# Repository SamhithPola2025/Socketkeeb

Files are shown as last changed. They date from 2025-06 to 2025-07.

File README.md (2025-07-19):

# Socketkeeb
Socketkeeb (keyboard) is a custom keyboard I designed in 4 days from PCB to CAD for HackClub's Highway program.
This keyboard was inspired by my need for a keyboard that had low profile switches because those are my favorite type of switches but I could not find a budget one anywhere, so I said why not just make it myself, because that's the solution to most things in life unless its rocket science.

# Challenges
- Designing a PCB compatible with both RP2040 and Kailh Choc switches  
- Sourcing components from multiple vendors while managing shipping costs  
- Ensuring 3D printed keycaps fit properly on low-profile switches  
- Aligning stabilizers and switches without a plate (plateless design quirks)  

# Why I made this
- I wanted a fully custom keyboard with low-profile Choc switches and RP2040 brain  
- I wanted to learn about PCB design, BOM creation, and firmware flashing  
- I like the idea of 3D printing keycaps for a unique personal touch  
- It’s a fun project to build something that’s truly mine from scratch  

# What went good
- Successfully generated a clean BOM and Markdown table for GitHub  
- Found all parts at reasonable prices from trusted vendors  
- 3D printed keycaps turned out better than expected using PLA  
- The design workflow in CAD + PCB tools was smoother than I thought

# BOM: (In BOM.csv too)
| Reference | Quantity | Value | Footprint | Manufacturer | Part Number | Description | Unit Price (USD) | Total Price (USD) | Source Link |
|---|---|---|---|---|---|---|---|---|---|
| STAB | 1 set | n/a | PCB Mount | Gateron | n/a | Gateron PCB-mounted stabilizer set (various sizes) | 8.00 | 8.00 | [Gateron](https://www.gateron.com/products/gateron-pcb-mounted-stabilizer?VariantsId=10208) |
| U1 | 1 | RP2040 | Pico W | Raspberry Pi | SC0918 | Raspberry Pi Pico W microcontroller | 7.65 | 7.65 | [DigiKey](https://www.digikey.com/en/products/detail/raspberry-pi/SC0918/16608263) |
| SW1-SW70 | 70 | Kailh Choc Violet | Kailh PG1350 | Kailh | PG1350 | Kailh low-profile Choc Violet switch (70 pcs) | 44.74 | 44.74 | [AliExpress](https://www.aliexpress.us/item/3256806826186563.html) |
| D1-D200 | 200 | 1N4148 | DO-35 | ON Semi | 1N4148 | 1N4148 100V 200mA diode (200 pcs) | 6.76 | 6.76 | [DigiKey](https://www.digikey.com/en/products/detail/onsemi/1N4148/458603) |
| KC1-KC70 | 70 | n/a | n/a | 3D printed | n/a | Custom 3D printed keycaps | 0.00 | 0.00 | n/a |
| **Subtotal** |  |  |  |  |  |  |  | **67.15** |  |
| **Estimated total (with shipping/tax rounded)** |  |  |  |  |  |  |  | **100.00** |  |

# Design Pictures:


Screenshot 2025-06-27 at 9 40 19 PM

# Build Pictures:
IMG_35EF4666-0DB9-4445-A45B-9BEA4F2A8813 2

## My printer broke down, not enough time for printing legion, have to go to Barcelona tommorow. Decided to 3D print what I could, and I got permission to submit demo form without keycaps. Hope that clears up a few things regarding the demo video!

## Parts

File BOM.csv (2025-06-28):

BOM
Reference | Quantity | Value | Footprint | Manufacturer | Part Number | Description | Unit Price (USD) | Total Price (USD) | Source Link
STAB | 1 set | N/a | PCB Mount | Gateron | N/a | Gateron PCB-mounted stabilizer set (various sizes) | 8.00 | 8.00 | https://www.gateron.com/products/gateron-pcb-mounted-stabilizer?VariantsId=10208
U1 | 1 | RP2040 | Pico W | Raspberry Pi | SC0918 | Raspberry Pi Pico W microcontroller | 7.65 | 7.65 | https://www.digikey.com/en/products/detail/raspberry-pi/SC0918/16608263
SW1-SW70 | 70 | Kailh Choc Violet | Kailh PG1350 | Kailh | PG1350 | Kailh low-profile Choc Violet switch (70 pcs) | 44.74 | 44.74 | https://www.aliexpress.us/item/3256806826186563.html
D1-D200 | 200 | 1N4148 | DO-35 | ON Semi | 1N4148 | 1N4148 100V 200mA diode (200 pcs) | 6.76 | 6.76 | https://www.digikey.com/en/products/detail/onsemi/1N4148/458603
KC1-KC70 | 70 | N/a | N/a | 3D printed | N/a | Custom 3D printed keycaps | 0.00 | 0.00 | N/a
PCB (full pcb) | 1 | PCB | N/a | JLCPCB | N/a | JLCPCB quote for the keyboard PCB | 20.00 | 20.00
Subtotal |  |  |  |  |  |  |  | 67.15
Estimated total (with shipping/tax rounded) |  |  |  |  |  |  |  | $100 (tax+shipping added and probably it all wont be used)

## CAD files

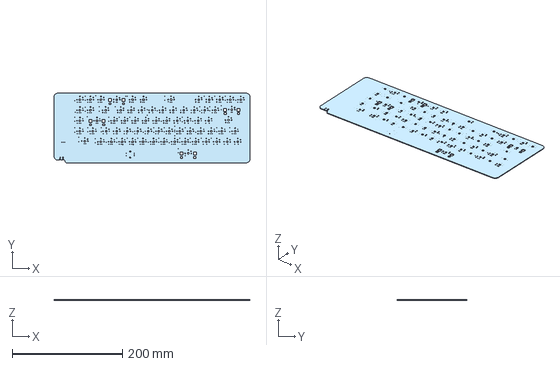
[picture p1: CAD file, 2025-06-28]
CAD/PLATESTEP.step
355.0 x 126.2 x 1.00 mm

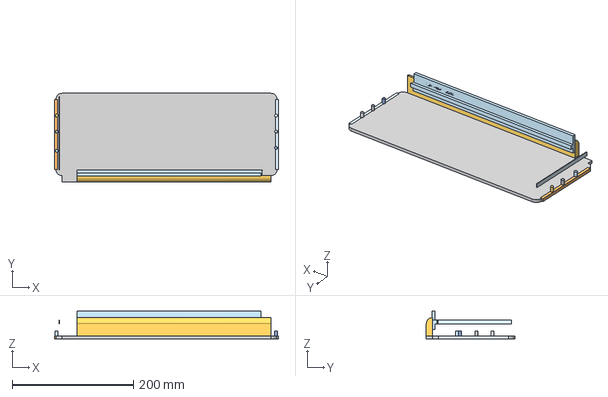
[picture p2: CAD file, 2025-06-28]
CAD/CASEBOTTOMBACKSIDESTEP.step
370.0 x 146.2 x 45.8 mm

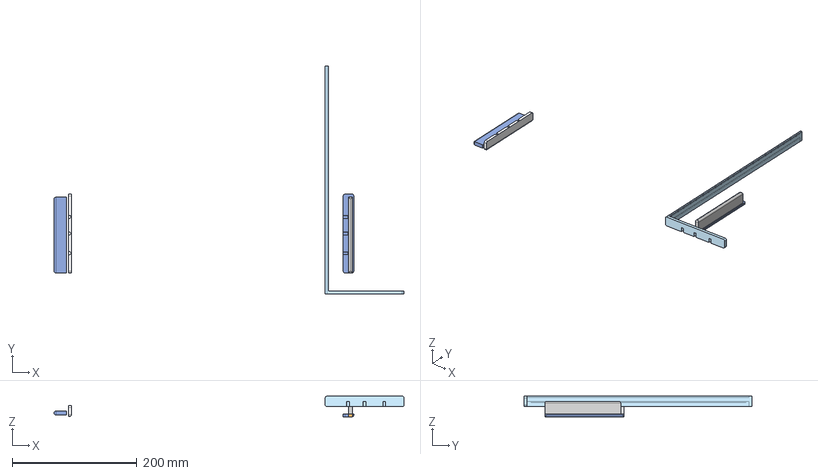
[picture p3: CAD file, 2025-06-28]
CAD/CASEWALLSSTEP.step
560.1 x 365.0 x 33.3 mm

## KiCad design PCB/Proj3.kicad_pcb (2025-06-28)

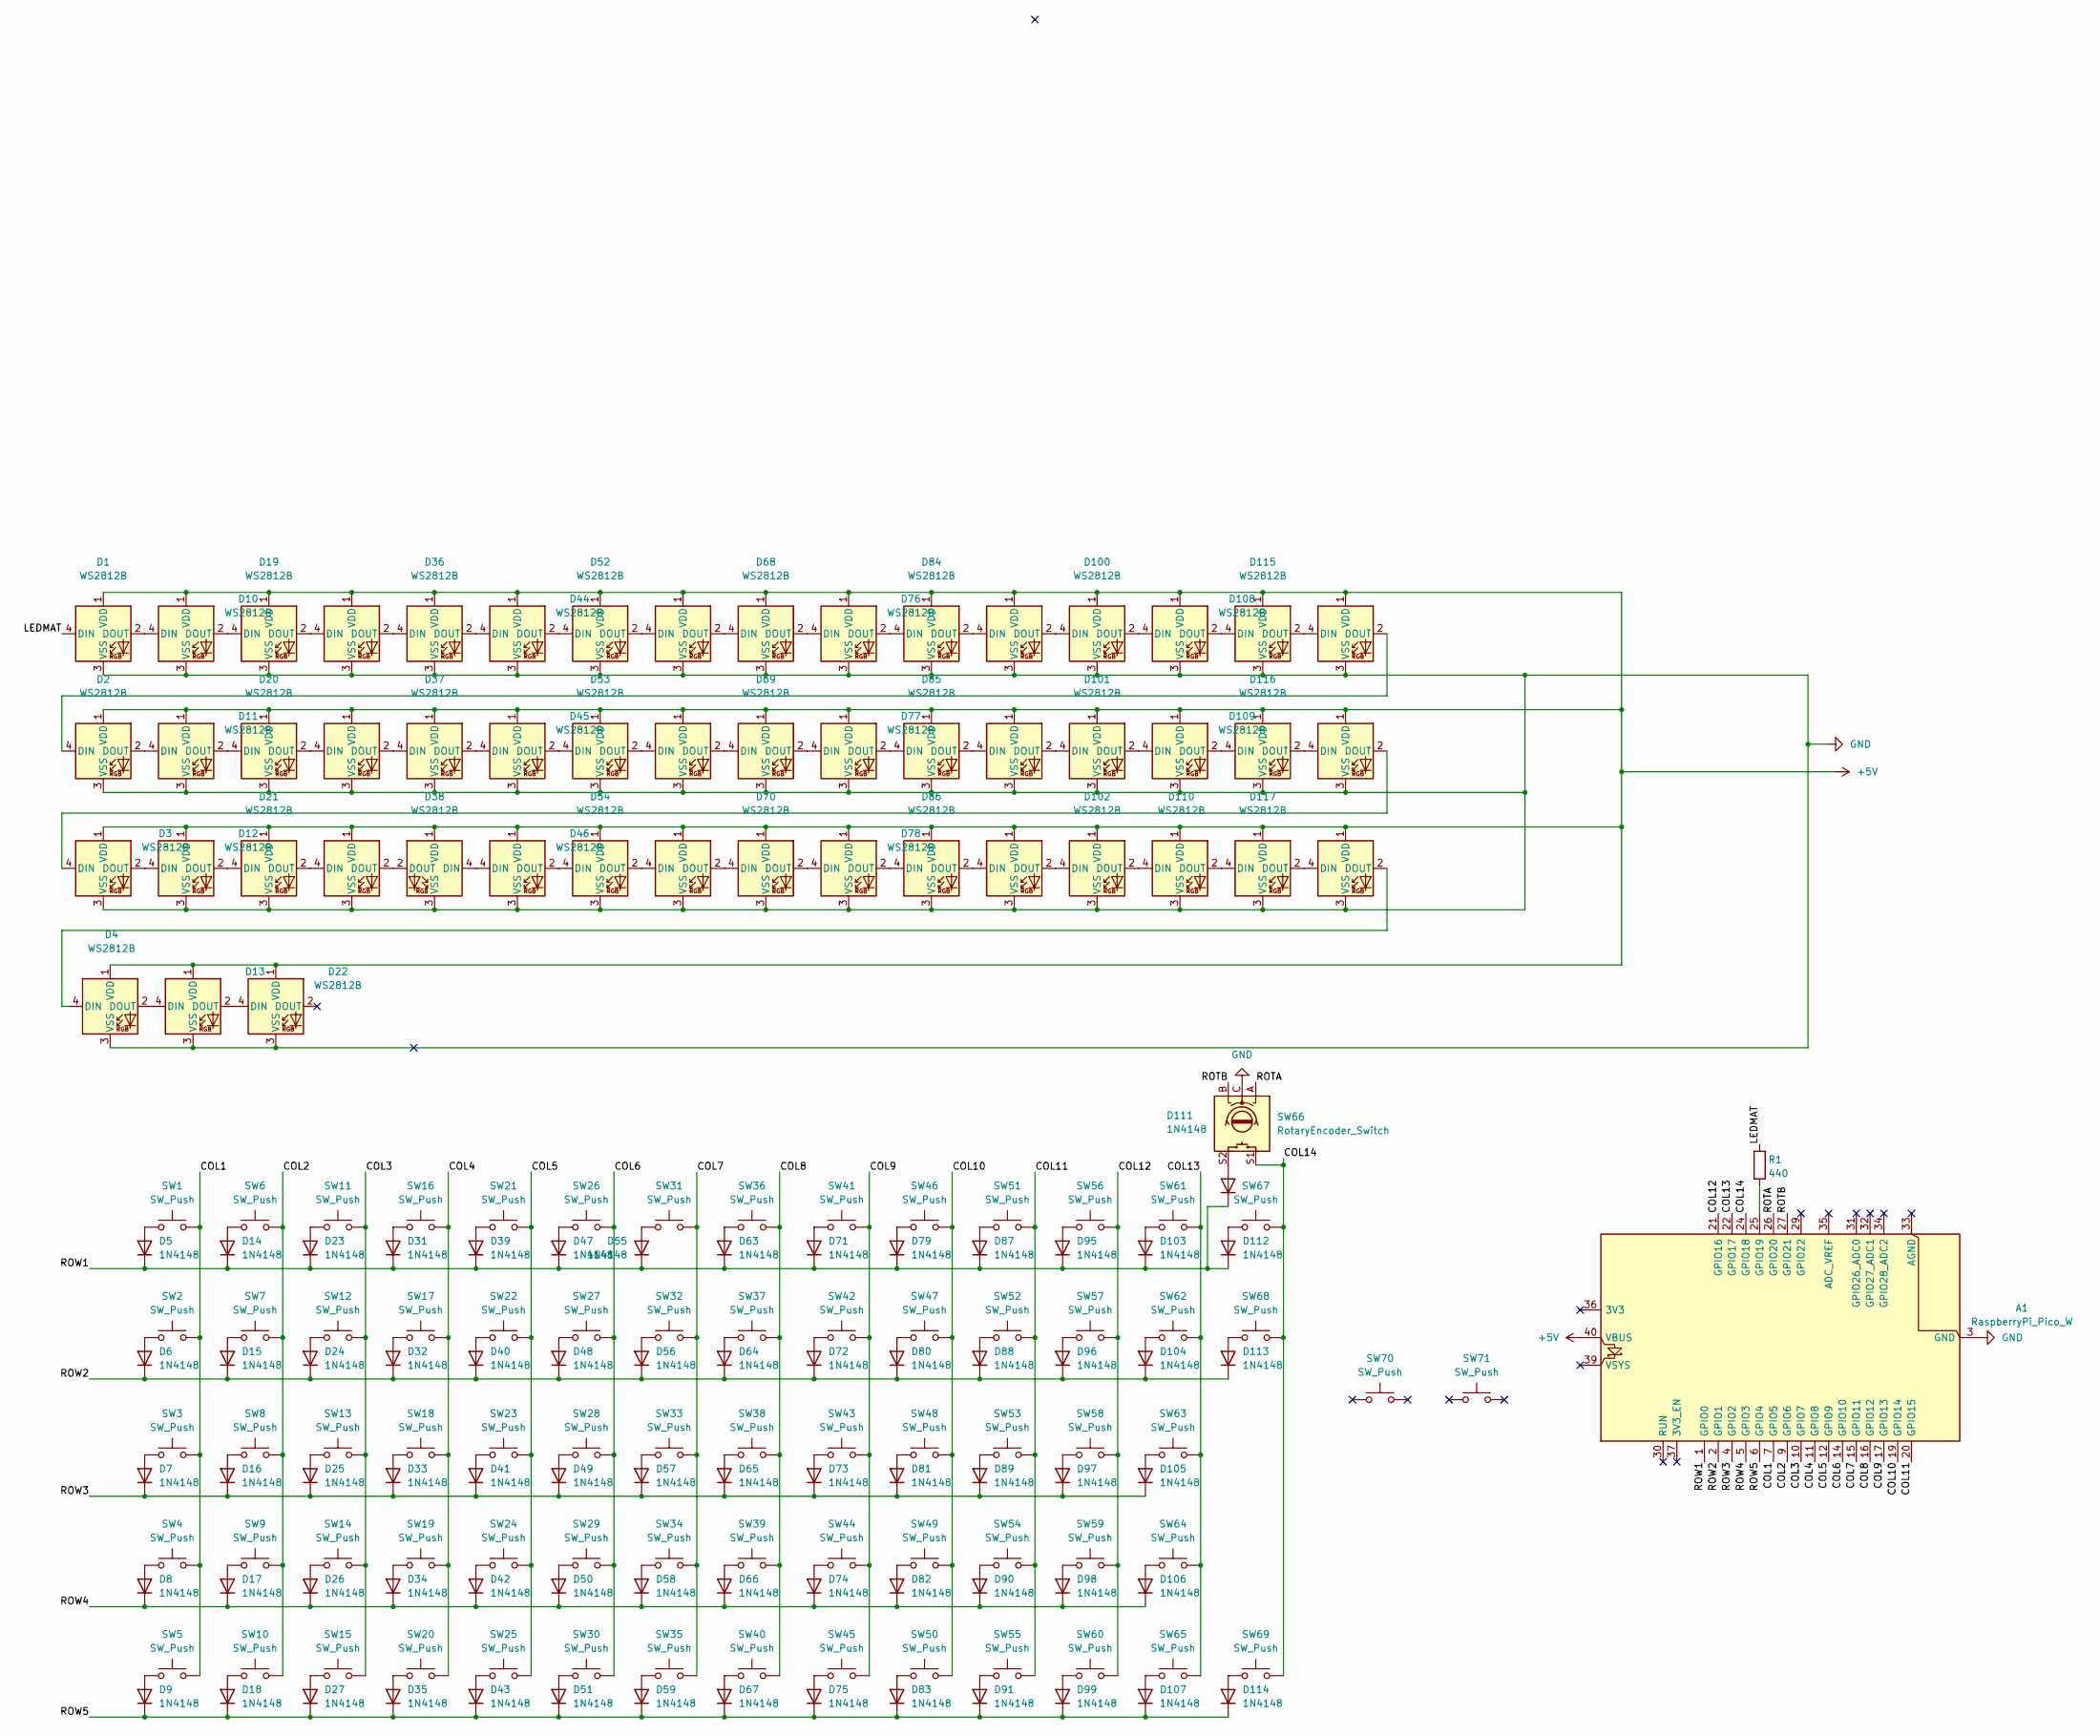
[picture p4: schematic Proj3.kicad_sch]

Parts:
A1: RaspberryPi_Pico_W; RaspberryPi_Pico_W_SMD_HandSolder
D1, D2, D3, D4, D10, D11, D12, D13, D19, D20, D21, D22, D28, D29, D30, D36, D37, D38, D44, D45, D46, D52, D53, D54, D60, D61, D62, D68, D69, D70, D76, D77, D78, D84, D85, D86, D92, D93, D94, D100, D101, D102, D108, D109, D110, D115, D116, D117, D118, D119, D120: WS2812B; LED_WS2812B_PLCC4_5.0x5.0mm_P3.2mm
D5, D6, D7, D8, D9, D14, D15, D16, D17, D18, D23, D24, D25, D26, D27, D31, D32, D33, D34, D35, D39, D40, D41, D42, D43, D47, D48, D49, D50, D51, D55, D56, D57, D58, D59, D63, D64, D65, D66, D67, D71, D72, D73, D74, D75, D79, D80, D81, D82, D83, D87, D88, D89, D90, D91, D95, D96, D97, D98, D99, D103, D104, D105, D106, D107, D111, D112, D113, D114: 1N4148; D_DO-35_SOD27_P7.62mm_Horizontal
R1: 440; R_0805_2012Metric
SW1, SW2, SW4, SW5, SW6, SW7, SW9, SW10, SW11, SW12, SW13, SW14, SW15, SW16, SW17, SW18, SW19, SW20, SW21, SW22, SW23, SW24, SW25, SW26, SW27, SW28, SW29, SW30, SW31, SW32, SW33, SW34, SW35, SW36, SW37, SW38, SW39, SW40, SW41, SW42, SW43, SW44, SW45, SW46, SW47, SW48, SW49, SW50, SW51, SW52, SW53, SW54, SW55, SW56, SW57, SW58, SW59, SW60, SW61, SW62, SW63, SW64, SW65, SW67, SW69, SW70, SW71: SW_Push; Kailh-PG1350-1u
SW3: SW_Push; Kailh-PG1350-1.5u
SW8: SW_Push; Kailh-PG1350-1.75u-NoLED
SW66: RotaryEncoder_Switch; RotaryEncoder_Alps_EC11E-Switch_Vertical_H20mm
SW68: SW_Push; Kailh-PG1350-2u

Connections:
+5V: A1.40 (VBUS), D1.1 (VDD), D2.1 (VDD), D3.1 (VDD), D4.1 (VDD), D10.1 (VDD), D11.1 (VDD), D12.1 (VDD), D13.1 (VDD), D19.1 (VDD), D20.1 (VDD), D21.1 (VDD), D22.1 (VDD), D28.1 (VDD), D29.1 (VDD), D30.1 (VDD), D36.1 (VDD), D37.1 (VDD), D38.1 (VDD), D44.1 (VDD), D45.1 (VDD), D46.1 (VDD), D52.1 (VDD), D53.1 (VDD), D54.1 (VDD), D60.1 (VDD), D61.1 (VDD), D62.1 (VDD), D68.1 (VDD), D69.1 (VDD), D70.1 (VDD), D76.1 (VDD), D77.1 (VDD), D78.1 (VDD), D84.1 (VDD), D85.1 (VDD), D86.1 (VDD), D92.1 (VDD), D93.1 (VDD), D94.1 (VDD), D100.1 (VDD), D101.1 (VDD), D102.1 (VDD), D108.1 (VDD), D109.1 (VDD), D110.1 (VDD), D115.1 (VDD), D116.1 (VDD), D117.1 (VDD), D118.1 (VDD), D119.1 (VDD), D120.1 (VDD)
/COL1: A1.7 (GPIO5), SW1.2, SW2.2, SW3.2, SW4.2, SW5.2
/COL2: A1.9 (GPIO6), SW6.2, SW7.2, SW8.2, SW9.2, SW10.2
/COL3: A1.10 (GPIO7), SW11.2, SW12.2, SW13.2, SW14.2, SW15.2
/COL4: A1.11 (GPIO8), SW16.2, SW17.2, SW18.2, SW19.2, SW20.2
/COL5: A1.12 (GPIO9), SW21.2, SW22.2, SW23.2, SW24.2, SW25.2
/COL6: A1.14 (GPIO10), SW26.2, SW27.2, SW28.2, SW29.2, SW30.2
/COL7: A1.15 (GPIO11), SW31.2, SW32.2, SW33.2, SW34.2, SW35.2
/COL8: A1.16 (GPIO12), SW36.2, SW37.2, SW38.2, SW39.2, SW40.2
/COL9: A1.17 (GPIO13), SW41.2, SW42.2, SW43.2, SW44.2, SW45.2
/COL10: A1.19 (GPIO14), SW46.2, SW47.2, SW48.2, SW49.2, SW50.2
/COL11: A1.20 (GPIO15), SW51.2, SW52.2, SW53.2, SW54.2, SW55.2
/COL12: A1.21 (GPIO16), SW56.2, SW57.2, SW58.2, SW59.2, SW60.2
/COL13: A1.22 (GPIO17), SW61.2, SW62.2, SW63.2, SW64.2, SW65.2
/COL14: A1.24 (GPIO18), SW66.S1, SW67.2, SW68.2, SW69.2
/LEDMAT: D1.4 (DIN), R1.1
/ROTA: A1.26 (GPIO20), SW66.A
/ROTB: A1.27 (GPIO21), SW66.B
/ROW1: A1.1 (GPIO0), D5.1 (K), D14.1 (K), D23.1 (K), D31.1 (K), D39.1 (K), D47.1 (K), D55.1 (K), D63.1 (K), D71.1 (K), D79.1 (K), D87.1 (K), D95.1 (K), D103.1 (K), D111.1 (K), D112.1 (K)
/ROW2: A1.2 (GPIO1), D6.1 (K), D15.1 (K), D24.1 (K), D32.1 (K), D40.1 (K), D48.1 (K), D56.1 (K), D64.1 (K), D72.1 (K), D80.1 (K), D88.1 (K), D96.1 (K), D104.1 (K), D113.1 (K)
/ROW3: A1.4 (GPIO2), D7.1 (K), D16.1 (K), D25.1 (K), D33.1 (K), D41.1 (K), D49.1 (K), D57.1 (K), D65.1 (K), D73.1 (K), D81.1 (K), D89.1 (K), D97.1 (K), D105.1 (K)
/ROW4: A1.5 (GPIO3), D8.1 (K), D17.1 (K), D26.1 (K), D34.1 (K), D42.1 (K), D50.1 (K), D58.1 (K), D66.1 (K), D74.1 (K), D82.1 (K), D90.1 (K), D98.1 (K), D106.1 (K)
/ROW5: A1.6 (GPIO4), D9.1 (K), D18.1 (K), D27.1 (K), D35.1 (K), D43.1 (K), D51.1 (K), D59.1 (K), D67.1 (K), D75.1 (K), D83.1 (K), D91.1 (K), D99.1 (K), D107.1 (K), D114.1 (K)
GND: A1.3 (GND), A1.8 (GND), A1.13 (GND), A1.18 (GND), A1.23 (GND), A1.28 (GND), A1.38 (GND), D1.3 (VSS), D2.3 (VSS), D3.3 (VSS), D4.3 (VSS), D10.3 (VSS), D11.3 (VSS), D12.3 (VSS), D13.3 (VSS), D19.3 (VSS), D20.3 (VSS), D21.3 (VSS), D22.3 (VSS), D28.3 (VSS), D29.3 (VSS), D30.3 (VSS), D36.3 (VSS), D37.3 (VSS), D38.3 (VSS), D44.3 (VSS), D45.3 (VSS), D46.3 (VSS), D52.3 (VSS), D53.3 (VSS), D54.3 (VSS), D60.3 (VSS), D61.3 (VSS), D62.3 (VSS), D68.3 (VSS), D69.3 (VSS), D70.3 (VSS), D76.3 (VSS), D77.3 (VSS), D78.3 (VSS), D84.3 (VSS), D85.3 (VSS), D86.3 (VSS), D92.3 (VSS), D93.3 (VSS), D94.3 (VSS), D100.3 (VSS), D101.3 (VSS), D102.3 (VSS), D108.3 (VSS), D109.3 (VSS), D110.3 (VSS), D115.3 (VSS), D116.3 (VSS), D117.3 (VSS), D118.3 (VSS), D119.3 (VSS), D120.3 (VSS), SW66.C
unnamed: A1.25 (GPIO19), R1.2
unnamed: D1.2 (DOUT), D10.4 (DIN)
unnamed: D5.2 (A), SW1.1
unnamed: D6.2 (A), SW2.1
unnamed: D7.2 (A), SW3.1
unnamed: D8.2 (A), SW4.1
unnamed: D9.2 (A), SW5.1
unnamed: D10.2 (DOUT), D19.4 (DIN)
unnamed: D2.2 (DOUT), D11.4 (DIN)
unnamed: D11.2 (DOUT), D20.4 (DIN)
unnamed: D3.2 (DOUT), D12.4 (DIN)
unnamed: D12.2 (DOUT), D21.4 (DIN)
unnamed: D4.2 (DOUT), D13.4 (DIN)
unnamed: D13.2 (DOUT), D22.4 (DIN)
unnamed: D14.2 (A), SW6.1
unnamed: D15.2 (A), SW7.1
unnamed: D16.2 (A), SW8.1
unnamed: D17.2 (A), SW9.1
unnamed: D18.2 (A), SW10.1
unnamed: D19.2 (DOUT), D28.4 (DIN)
unnamed: D20.2 (DOUT), D29.4 (DIN)
unnamed: D21.2 (DOUT), D30.4 (DIN)
unnamed: D23.2 (A), SW11.1
unnamed: D24.2 (A), SW12.1
unnamed: D25.2 (A), SW13.1
unnamed: D26.2 (A), SW14.1
unnamed: D27.2 (A), SW15.1
unnamed: D28.2 (DOUT), D36.4 (DIN)
unnamed: D29.2 (DOUT), D37.4 (DIN)
unnamed: D30.2 (DOUT), D38.2 (DOUT)
unnamed: D31.2 (A), SW16.1
unnamed: D32.2 (A), SW17.1
unnamed: D33.2 (A), SW18.1
unnamed: D34.2 (A), SW19.1
unnamed: D35.2 (A), SW20.1
unnamed: D36.2 (DOUT), D44.4 (DIN)
unnamed: D37.2 (DOUT), D45.4 (DIN)
unnamed: D38.4 (DIN), D46.4 (DIN)
unnamed: D39.2 (A), SW21.1
unnamed: D40.2 (A), SW22.1
unnamed: D41.2 (A), SW23.1
unnamed: D42.2 (A), SW24.1
unnamed: D43.2 (A), SW25.1
unnamed: D44.2 (DOUT), D52.4 (DIN)
unnamed: D45.2 (DOUT), D53.4 (DIN)
unnamed: D46.2 (DOUT), D54.4 (DIN)
unnamed: D47.2 (A), SW26.1
unnamed: D48.2 (A), SW27.1
unnamed: D49.2 (A), SW28.1
unnamed: D50.2 (A), SW29.1
unnamed: D51.2 (A), SW30.1
unnamed: D52.2 (DOUT), D60.4 (DIN)
unnamed: D53.2 (DOUT), D61.4 (DIN)
unnamed: D54.2 (DOUT), D62.4 (DIN)
unnamed: D55.2 (A), SW31.1
unnamed: D56.2 (A), SW32.1
unnamed: D57.2 (A), SW33.1
unnamed: D58.2 (A), SW34.1
unnamed: D59.2 (A), SW35.1
unnamed: D60.2 (DOUT), D68.4 (DIN)
unnamed: D61.2 (DOUT), D69.4 (DIN)
unnamed: D62.2 (DOUT), D70.4 (DIN)
unnamed: D63.2 (A), SW36.1
unnamed: D64.2 (A), SW37.1
unnamed: D65.2 (A), SW38.1
unnamed: D66.2 (A), SW39.1
unnamed: D67.2 (A), SW40.1
unnamed: D68.2 (DOUT), D76.4 (DIN)
unnamed: D69.2 (DOUT), D77.4 (DIN)
unnamed: D70.2 (DOUT), D78.4 (DIN)
unnamed: D71.2 (A), SW41.1
unnamed: D72.2 (A), SW42.1
unnamed: D73.2 (A), SW43.1
unnamed: D74.2 (A), SW44.1
unnamed: D75.2 (A), SW45.1
unnamed: D76.2 (DOUT), D84.4 (DIN)
unnamed: D77.2 (DOUT), D85.4 (DIN)
unnamed: D78.2 (DOUT), D86.4 (DIN)
unnamed: D79.2 (A), SW46.1
unnamed: D80.2 (A), SW47.1
unnamed: D81.2 (A), SW48.1
unnamed: D82.2 (A), SW49.1
unnamed: D83.2 (A), SW50.1
unnamed: D84.2 (DOUT), D92.4 (DIN)
unnamed: D85.2 (DOUT), D93.4 (DIN)
unnamed: D86.2 (DOUT), D94.4 (DIN)
unnamed: D87.2 (A), SW51.1
unnamed: D88.2 (A), SW52.1
unnamed: D89.2 (A), SW53.1
unnamed: D90.2 (A), SW54.1
unnamed: D91.2 (A), SW55.1
unnamed: D95.2 (A), SW56.1
unnamed: D96.2 (A), SW57.1
unnamed: D97.2 (A), SW58.1
unnamed: D98.2 (A), SW59.1
unnamed: D99.2 (A), SW60.1
unnamed: D92.2 (DOUT), D100.4 (DIN)
unnamed: D100.2 (DOUT), D108.4 (DIN)
unnamed: D93.2 (DOUT), D101.4 (DIN)
unnamed: D101.2 (DOUT), D109.4 (DIN)
unnamed: D94.2 (DOUT), D102.4 (DIN)
unnamed: D102.2 (DOUT), D110.4 (DIN)
unnamed: D103.2 (A), SW61.1
unnamed: D104.2 (A), SW62.1
unnamed: D105.2 (A), SW63.1
unnamed: D106.2 (A), SW64.1
unnamed: D107.2 (A), SW65.1
unnamed: D108.2 (DOUT), D115.4 (DIN)
unnamed: D109.2 (DOUT), D116.4 (DIN)
unnamed: D110.2 (DOUT), D117.4 (DIN)
unnamed: D111.2 (A), SW66.S2
unnamed: D112.2 (A), SW67.1
unnamed: D113.2 (A), SW68.1
unnamed: D114.2 (A), SW69.1
unnamed: D115.2 (DOUT), D118.4 (DIN)
unnamed: D116.2 (DOUT), D119.4 (DIN)
unnamed: D117.2 (DOUT), D120.4 (DIN)
unnamed: D2.4 (DIN), D118.2 (DOUT)
unnamed: D3.4 (DIN), D119.2 (DOUT)
unnamed: D4.4 (DIN), D120.2 (DOUT)

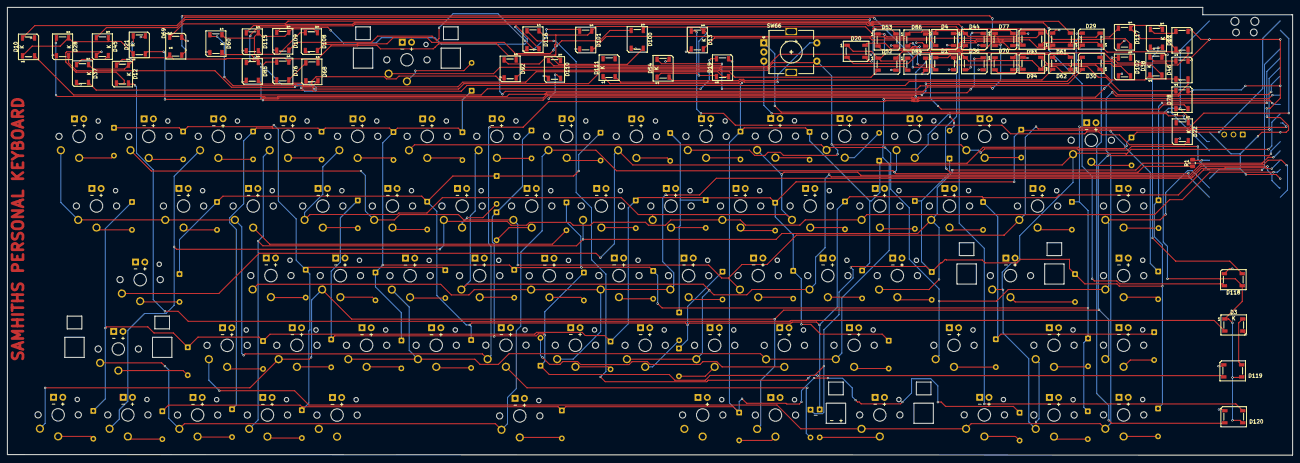
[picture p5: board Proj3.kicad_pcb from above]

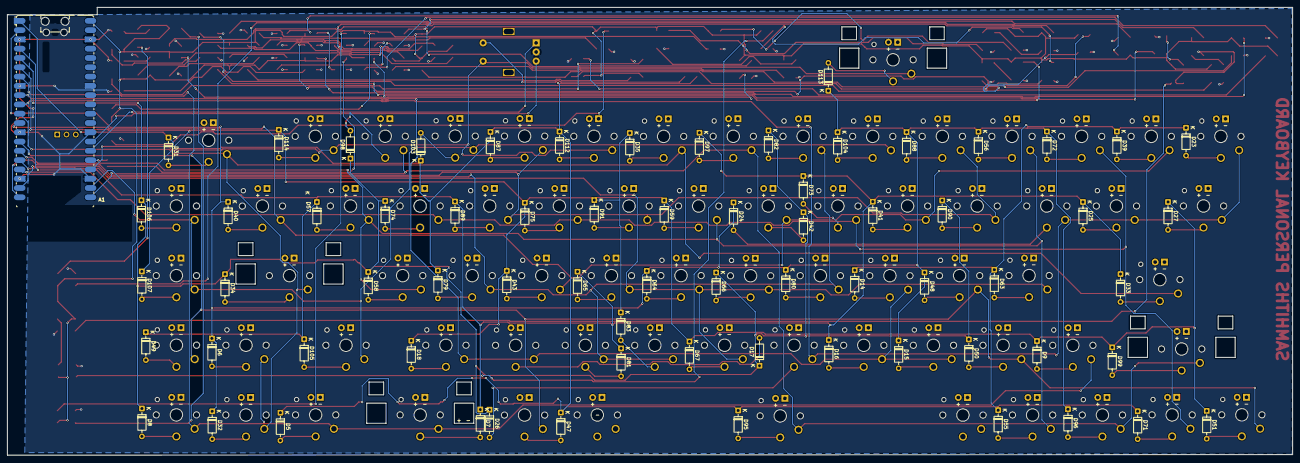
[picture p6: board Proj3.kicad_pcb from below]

Board: 2 copper layers, 351.6 x 122.5 mm, 193 parts (69 on the bottom side), 144 nets.

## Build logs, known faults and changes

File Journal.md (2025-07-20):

### COMPLETE TIME TAKEN: ~20 HRS (so far)

This file is where I store all my journaling for my keyboard starting from day one to the end of the building, this will be updated occasionally (every day).

## DESIGNING (4 DAYS) 
## ~30 HRS

# Day 1:
~ 4hrs
Monday, June 30th, 2025
Today was just a bunch of schematic things and starting with my pcb layout, for the schematic I had to pull a funny and use a different MCU than what I used for hackpad since it was short by exactly 1 GPIO and I didnt want to remove a row or column from my matrix as this is already a 65% keyboard.
My PCB layout was pretty simple well I thought until I had to reset the entire thing like 4 times. I decided to go with some low profile switches which are the Kailh Choc switches (V1 even though its outdated I like its feel more). And I ultimately decided to go plateless since these switches are compatible with a plateless build and it would also be nice to not have to make a plate for this monstrosity of a layout that I had going on here.
 (I also added some LEDS into the equation, and for some reason didnt use SW_PUSH 45 degree but used the normal ones that doesnt matter though.)
 (I had to mess with some keepout zone related stuff in the PCB editor too because it just didnt work out since the keepout zone for my MCU is absolutely huge. And as you can see the routing is a complete mess that I decided to fix later)

# Day 2:
~ 5hrs
Tuesday, July 1st, 2025
Today was finishing the full PCB layout and I plan for the next 2 days to be purely CAD related things. I also decided to do some work on my BOM and that turned out to be simple (check BOM.csv). The full PCB layout had some issues and I decided to go with the option of using some stabilisers but replacing some with dead switches that dont have any electrical connection, because it turns out the PCB mounted stabilisers that exist for the switch model that I am using is very old and is very expensive online for bigger sizes, so easy workaround.
But if we put aside the challenges that I had, the upsides were that I got to finish my layout today and export the model into CAD (didnt do anything else in CAD today). But I also spent a while looking for the perfect footprint and things so that I didnt have a shortage of actual parts to buy online. I decided not to go with hotswap because 1: Im not going to remove these keys and 2: I dont want to deal with the hotswap sockets for the type of switches Im using its a lot more of a pain than you would think and 3: Whats the fun in that when you could torture yourself into soldering on all of your switches individually?
 (The routing of my PCB took a very long time so I loaded it into freerouting which did like half of it before breaking so I spent another hour doing the other half and cleaning up the mess that freerouting made, lesson learned.)

# Day 3:
~ 5hrs
Wednesday, July 2nd, 2025
Today was a lot of CAD related things, and it took me a while to decide on a plateless design and I also spent a lot of time deleting things because that's just how CAD goes. I imported my PCB model into Onshape and started designing a case, I wanted this to be a unique but cool case so that I did not have to redo this because it was too "simple" like the other keyboards. I like this case design because it is simple and the rounded edges give it a sleek look, I used a little peg system to hold it together so it just slides like an apple box instead of screws which are kind of annoying in some ways, I can always integrate screws easily but since it stays on my desk I don't need something too permanent.

Today I also refined the PCB a lot and changed some diodes and moved them around a lot because it took a while for me to get them right and for some reason some diodes ended up as LED's??? I dont even know how that ended up happening.

# Day 4:
~ 6hrs
Thursday, July 3rd, 2025
This might as well be the last day of my designing, this has been quite a ride and I learnt a lot from designing this, plus an awesome keyboard. Today was just a bunch of CAD stuff and polishing CAD and fixing any fixing issues, I also worked a lot on my final model that had all the switches and keycaps and I also found a lot of cheaper components online and updated my BOM. I made the final render that is in the ReadMe.md. I made the keycaps and stole a few and I will be 3D printing these to save costs. I also ran a quote on JLCPCB and added that to my BOM.
Screenshot 2025-06-27 at 9 40 19 PM

## BUILDING (2 DAYS)
## ~ 10 HRS
None of the parts arrived yet, sad. Will update this part when my parts arrive and I start building!

# Day 5:
~ 4.5 hrs
Friday, July 17, 2025
First day of building, all the parts arrived, today was mostly just bending, twisting, putting in and soldering diodes, key switches were easy, and for the RP2035 board that I was using (Pi Pico 2W), it broke and I had to order another amazon overnight, but it came in time so I soldered that on today, 3 pads also ripped off when desoldering the old one but I was super lucky as all 3 of those pads were no connects, meaning there is no issue if they rip off, (though it is a sign I need to get better at soldering.) Today the entire PCB finished and I started some 3D prints. I also got the cap for the rotary encoder on because why not.


# Day 6:
~ 5.5 hrs
Friday, July 18, 2025
Second day of building and hopefully last, ran into a few problems here, my printer broke down, not enough time for printing legion, have to go to Barcelona tommorow. Decided to 3D print what I could, and I got permission to submit demo form without keycaps, so that made things a lot easier. I used some other strong material to hold up the rest of the case, and I also uploaded some firmware, I used KMK and spent a while mapping keys, which is probably what took the most amount of time today. 



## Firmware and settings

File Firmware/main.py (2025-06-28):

import time
from machine import Pin # Import the Pin class for GPIO control

# --- Configuration based on your Schematic ---
# Define the GPIO pins connected to the Rows and Columns of your matrix.
# These correspond to the pins on the "ReguLar" (ESP32) component in your schematic.
# We will use the Pico W's GPIO numbers directly.

# Based on connections to "ReguLar" (ESP32) in the schematic:
# Rows connected to: IO10, IO11, IO12, IO13
# In MicroPython on Pico, these are just GPIO10, GPIO11, etc.
ROW_PINS_GPIO = [10, 11, 12, 13] 

# Columns connected to: IO34, IO35, IO36, IO37, IO38, IO39, IO40, IO41, IO42, IO43, IO44, IO45, IO46
# Note: Schematic shows COL0-COL12. Assuming they map sequentially to these IO pins.
# These are valid GPIO numbers on the Pico W.
COLUMN_PINS_GPIO = [34, 35, 36, 37, 38, 39, 40, 41, 42, 43, 44, 45, 46]

# Key map: A simple representation of what character each key represents.
# This assumes a standard keyboard layout for a 4x13 matrix.
KEY_MAP = [
    ['Q', 'W', 'E', 'R', 'T', 'Y', 'U', 'I', 'O', 'P', '[', ']', '\\'], # ROW0
    ['A', 'S', 'D', 'F', 'G', 'H', 'J', 'K', 'L', ';', "'", 'Enter', ' '], # ROW1 (Space placeholder)
    ['Z', 'X', 'C', 'V', 'B', 'N', 'M', ',', '.', '/', 'Shift', 'Up', ' '], # ROW2 (Up Arrow placeholder)
    ['Ctrl', 'Win', 'Alt', 'Space', ' ', ' ', ' ', ' ', ' ', ' ', 'Left', 'Down', 'Right'] # ROW3 (Space, arrows placeholders)
]

# For the Rotary Encoder Switch (SW70 in your schematic)
# This is typically just another switch in the matrix or a separate GPIO.
# If SW70 is wired as a normal matrix switch (e.g., COL11, ROW2 as implied in the top part of your schematic logic),
# it's handled by the matrix scan.
# If it's on a dedicated pin (e.g., IO47 for the 'ENC' signal shown), we'd read that directly.
# Assuming 'ENC' (IO47) is a separate input for the switch press.
ENCODER_SWITCH_PIN_GPIO = 47 # Assuming this maps to the 'ENC' signal on the ESP32

# --- Rotary Encoder Rotation Pins (New for Volume Knob) ---
# Assuming these are connected to available GPIOs on your Pico W.
ENCODER_A_PIN_GPIO = 26 # Connect encoder CLK/A pin here
ENCODER_B_PIN_GPIO = 27 # Connect encoder DT/B pin here

# --- Pin Objects Initialization ---
# Create Pin objects for rows and columns.
row_pins = [Pin(gpio, Pin.OUT) for gpio in ROW_PINS_GPIO]
column_pins = [Pin(gpio, Pin.IN, Pin.PULL_UP) for gpio in COLUMN_PINS_GPIO]
encoder_switch_pin = Pin(ENCODER_SWITCH_PIN_GPIO, Pin.IN, Pin.PULL_UP)

# Rotary Encoder Pin Objects
# These usually need pull-ups as well if your encoder module doesn't have them
encoder_a_pin = Pin(ENCODER_A_PIN_GPIO, Pin.IN, Pin.PULL_UP)
encoder_b_pin = Pin(ENCODER_B_PIN_GPIO, Pin.IN, Pin.PULL_UP)

# Global variables to track encoder state for rotation detection
last_encoder_a_state = None
# A small dictionary to store the last state of the encoder for each instance if multiple
# are needed, or simply global variables if only one encoder.

# --- MicroPython-Specific Functions ---

def scan_keyboard_matrix_pico():
    """
    Scans the keyboard matrix to detect pressed keys on Raspberry Pi Pico W.
    Uses MicroPython's machine.Pin objects.
    """
    pressed_keys = []
    
    # Ensure all row pins are high (inactive) initially
    for pin_obj in row_pins:
        pin_obj.value(1) # Set high (inactive)
    
    # Column pins are already configured as inputs with pull-ups during initialization.

    for r_idx, row_pin_obj in enumerate(row_pins):
        # Drive the current row low
        row_pin_obj.value(0) # Activate row
        time.sleep(0.005) # Small debounce delay for signal stabilization

        # Read the state of each column
        for c_idx, col_pin_obj in enumerate(column_pins):
            if col_pin_obj.value() == 0: # If column reads LOW, key is pressed
                try:
                    key = KEY_MAP[r_idx][c_idx]
                    pressed_keys.append(key)
                except IndexError:
                    # Fallback if KEY_MAP doesn't cover all matrix positions
                    pressed_keys.append(f"Key at ({r_idx}, {c_idx}) (No map)")
        
        # Deactivate the current row by setting it high again
        row_pin_obj.value(1) # Deactivate row

    return pressed_keys

def check_encoder_switch_pico():
    """
    Checks the state of the rotary encoder's push-button switch on Raspberry Pi Pico W.
    """
    # The encoder_switch_pin is already initialized with a pull-up.
    if encoder_switch_pin.value() == 0: # If button pulls pin LOW
        return "Encoder Button Pressed"
    else:
        return "Encoder Button Not Pressed"

def check_rotary_encoder_pico():
    """
    Detects rotary encoder rotation and direction (for volume knob).
    This is a basic polling method. For more robust detection (especially fast turns),
    interrupts are often preferred.
    """
    global last_encoder_a_state

    # Read current states of A and B pins
    current_a_state = encoder_a_pin.value()
    current_b_state = encoder_b_pin.value()

    # Initialize last_encoder_a_state on first run
    if last_encoder_a_state is None:
        last_encoder_a_state = current_a_state
        return None # No rotation detected yet

    # Only process if A state has changed
    if current_a_state != last_encoder_a_state:
        # Debounce: wait a tiny bit to ensure the signal is stable
        time.sleep_us(500) # Microseconds delay
        current_a_state = encoder_a_pin.value() # Re-read after debounce
        current_b_state = encoder_b_pin.value() # Re-read after debounce

        if current_a_state != last_encoder_a_state: # Confirm state change after debounce
            if current_b_state != current_a_state:
                # If B is different from A when A changes, it's one direction
                rotation_direction = "Clockwise (Volume Up)"
            else:
                # If B is the same as A when A changes, it's the other direction
                rotation_direction = "Counter-Clockwise (Volume Down)"
            last_encoder_a_state = current_a_state # Update last state
            return rotation_direction
    
    return None # No significant rotation detected

# --- Main Loop (Example for Pico W) ---
if __name__ == "__main__":
    # This block won't run directly on a desktop Python interpreter
    # because 'machine' module is for MicroPython.
    # To run this, upload it to your Raspberry Pi Pico W.

    print("Running Keyboard Matrix Scan & Rotary Encoder on Raspberry Pi Pico W (MicroPython)")
    print("----------------------------------------------------------------------------------")
    print("Connect to Pico's serial console to see output.")

    # Main loop to continuously scan for key presses and encoder rotations
    while True:
        current_pressed_keys = scan_keyboard_matrix_pico()
        current_encoder_button_state = check_encoder_switch_pico()
        rotation_event = check_rotary_encoder_pico()

        if current_pressed_keys:
            print(f"Keys Pressed: {current_pressed_keys}")
        
        if "Pressed" in current_encoder_button_state:
            print(f"Encoder Switch: {current_encoder_button_state}")
            
        if rotation_event:
            print(f"Encoder Rotated: {rotation_event}")
            
        time.sleep(0.05) # Scan every 50ms (adjust as needed for responsiveness vs. CPU usage)

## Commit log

2025-06-28 finale commit i think
    [BOM.csv, CASEBOTTOMBACKSIDESTEP.step, CASEWALLSSTEP.step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]
2025-06-28 fixed gerbers
    [Proj3-B_Adhesive.gbr, Proj3-B_Courtyard.gbr, Proj3-B_Cu.gbr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]
